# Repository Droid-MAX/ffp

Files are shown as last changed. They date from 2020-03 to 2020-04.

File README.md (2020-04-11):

# FFP: Flash/FPGA Programmer

FFP is a dead-simple USB to bidirectional SPI bridge for programming iCE40
FPGAs and their SPI flash. The hardware is an STM32F042 and not much else.
Firmware and host software is written in Rust.

The firmware additionally supports SWD via the CMSIS-DAP v1 protocol,
so many debuggers such as [probe-rs], [OpenOCD], and [pyOCD] are able to
use an FFP to debug and program Cortex-M and other microcontrollers.

[probe-rs]: https://probe.rs
[OpenOCD]: http://openocd.org
[pyOCD]: https://github.com/mbedmicro/pyOCD

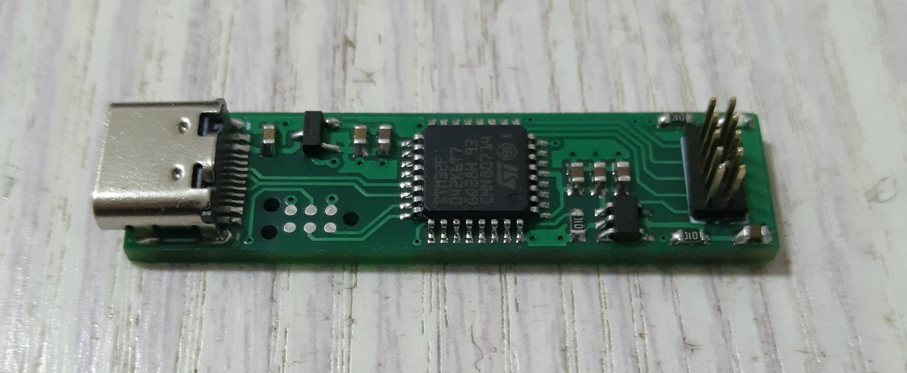
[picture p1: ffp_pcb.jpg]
Photo of FFP PCB


See [software/](software/) for the host-side software, [firmware/](firmware/)
for the embedded device firmware, and [hardware/](hardware/ffp/) for the
hardware design files.

## Pinout

The FFP r1 hardware uses a 5x2 pin 0.05"-pitch connector, which is also
commonly used for Cortex family microcontrollers for SWD and JTAG. The pinout
is deliberately compatible (though note `RESET` is moved) to allow hardware
reuse and for compatibility with tools such as TagConnect cables.

```ascii
          ______
    3v3 --|1  2|-- FLASH DI / FPGA DO / SWDIO
    GND --|3  4|-- CLK / SWCLK
    GND --|5  6|-- CS / SWO
   NULL --|7  8|-- FPGA nRST
    GND --|9 10|-- FLASH DO / FPGA DI / nRESET
          ------

```

This is the same pinout used by
[amp_flashprog](https://github.com/adamgreig/amp_flashprog), a custom firmware
for [Black Magic Probes](https://github.com/blacksphere/blackmagic) to bitbang
SPI to the same ends.

## Licence

Software and firmware is licensed under either of

* Apache License, Version 2.0 ([LICENSE-APACHE](LICENSE-APACHE) or
  http://www.apache.org/licenses/LICENSE-2.0)
* MIT license ([LICENSE-MIT](LICENSE-MIT) or http://opensource.org/licenses/MIT)

at your option.

Hardware design files are licensed under the Creative Commons Attribution
license ([CC-BY](https://creativecommons.org/licenses/by/4.0/)).

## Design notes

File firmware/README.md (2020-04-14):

# FFP Firmware

## Requirements

* You must have a working Rust compiler installed. Visit
[rustup.rs](https://rustup.rs) to install Rust.

* Your Rust toolchain needs the `thumbv6m-none-eabi` target installed:

```
rustup target add thumbv6m-none-eabi
```

## Building

Once Rust is installed, use Cargo to build:

```
cargo build --release
```

The resulting binary is an ELF file in
`target/thumbv6m-none-eabi/release/ffp_firmware` which can be programmed via
your usual programmer, or see below for generating a raw binary file and
bootloading over USB.

## Bootloading

You can reprogram the FFP using its built-in USB bootloader. You can use
[dfu-util](http://dfu-util.sourceforge.net/) or
[STM32CubeProg](https://www.st.com/en/development-tools/stm32cubeprog.html)
to perform the bootloading, both of which are available for Linux, MacOS, and
Windows.

To generate a binary file suitable for bootloading with dfu-util:
```
cargo build --release
arm-none-eabi-objcopy -O binary -S target/thumbv6m-none-eabi/release/ffp_firmware ffp.bin
```

STM32CubeProg can load data directly from the ELF file, but only if it has a
`.elf` extension. Simply copy the elf file:

```
cp target/thumbv6m-none-eabi/release/ffp_firmware ffp_firmware.elf
```

To put an already-programmed FFP device into bootload mode:
```
ffp bootload
```
Devices which have a totally erased flash will come up in bootloader mode
automatically.

To bootload using dfu-util:
```
dfu-suffix -a ffp.bin -v 0483 -p df11
dfu-util -a 0 -s 0x08000000 -D ffp.bin
```

To bootload using STM32CubeProg, open the `ffp_firmware.elf` file made above,
and download it to the FFP.

Reconnect the device after programming to load new firmware.

## Licence

Licensed under either of

* Apache License, Version 2.0 ([LICENSE-APACHE](../LICENSE-APACHE)
  or http://www.apache.org/licenses/LICENSE-2.0 )
* MIT license ([LICENSE-MIT](../LICENSE-MIT) or
  http://opensource.org/licenses/MIT )

at your option.

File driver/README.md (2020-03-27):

# FFP Platform-Specific Drivers

## Linux

Copy the `99-ffp.rules` file to your udev configuration directory and restart
udev:

```
sudo cp 99-ffp.rules /etc/udev/rules.d
sudo udevadm control --reload
```

Confirm you are in the `plugdev` group, or modify `99-ffp.rules` to use another
group or specify a specific user.

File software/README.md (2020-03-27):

# FFP Control Software

The control software for FFP runs on your computer and uses the FFP hardware to
program an FPGA or SPI flash. It is written in Rust.

## Building

```
cargo build --release
```

## Installing

FFP software can be installed using Cargo:

```
cargo install ffp
```

You'll need to set up permissions to access the USB device, see the [drivers
file](/driver/) for more details.

## Usage

Run `ffp help` for detailed usage. Commonly used commands:

* `ffp fpga program bitstream.bin`
* `ffp fpga reset`
* `ffp fpga power on`
* `ffp flash id`
* `ffp flash program bitstream.bin`

## Python Alternative

The prototype for this software was written as a Python script which is also
available ([prog.py](/scripts/prog.py)).

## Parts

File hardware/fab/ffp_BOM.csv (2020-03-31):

Comment | Description | Designator | Footprint | LibRef | Pins | Quantity | PartNumber | url
1µ | desc | C6,C5, | 0603 | libref | 2 | 2
100n | desc | C7,C4,C3,C2,C1, | 0603 | libref | 2 | 5
LED | desc | D1, | 0603-LED | libref | 2 | 1
STM32F042K6T7 | desc | IC1, | LQFP-32 | libref | 32 | 1
MCP1700 | desc | IC2, | SOT-23 | libref | 3 | 1
MIC2004-0_5YM5 | desc | IC3, | SOT-23-5 | libref | 5 | 1
10k | desc | R3,R2,R1, | 0603 | libref | 2 | 3
Through Hole Items
USB_C_Receptacle_USB2.0 | desc | J2, | USB-C_16Pin | libref | 18 | 1
PROG | desc | J3, | PinHeader_2x05_P1.27mm_Vertical | libref | 10 | 1
SWD_TC | desc | P1, | TC2030-NL | libref | 9 | 1

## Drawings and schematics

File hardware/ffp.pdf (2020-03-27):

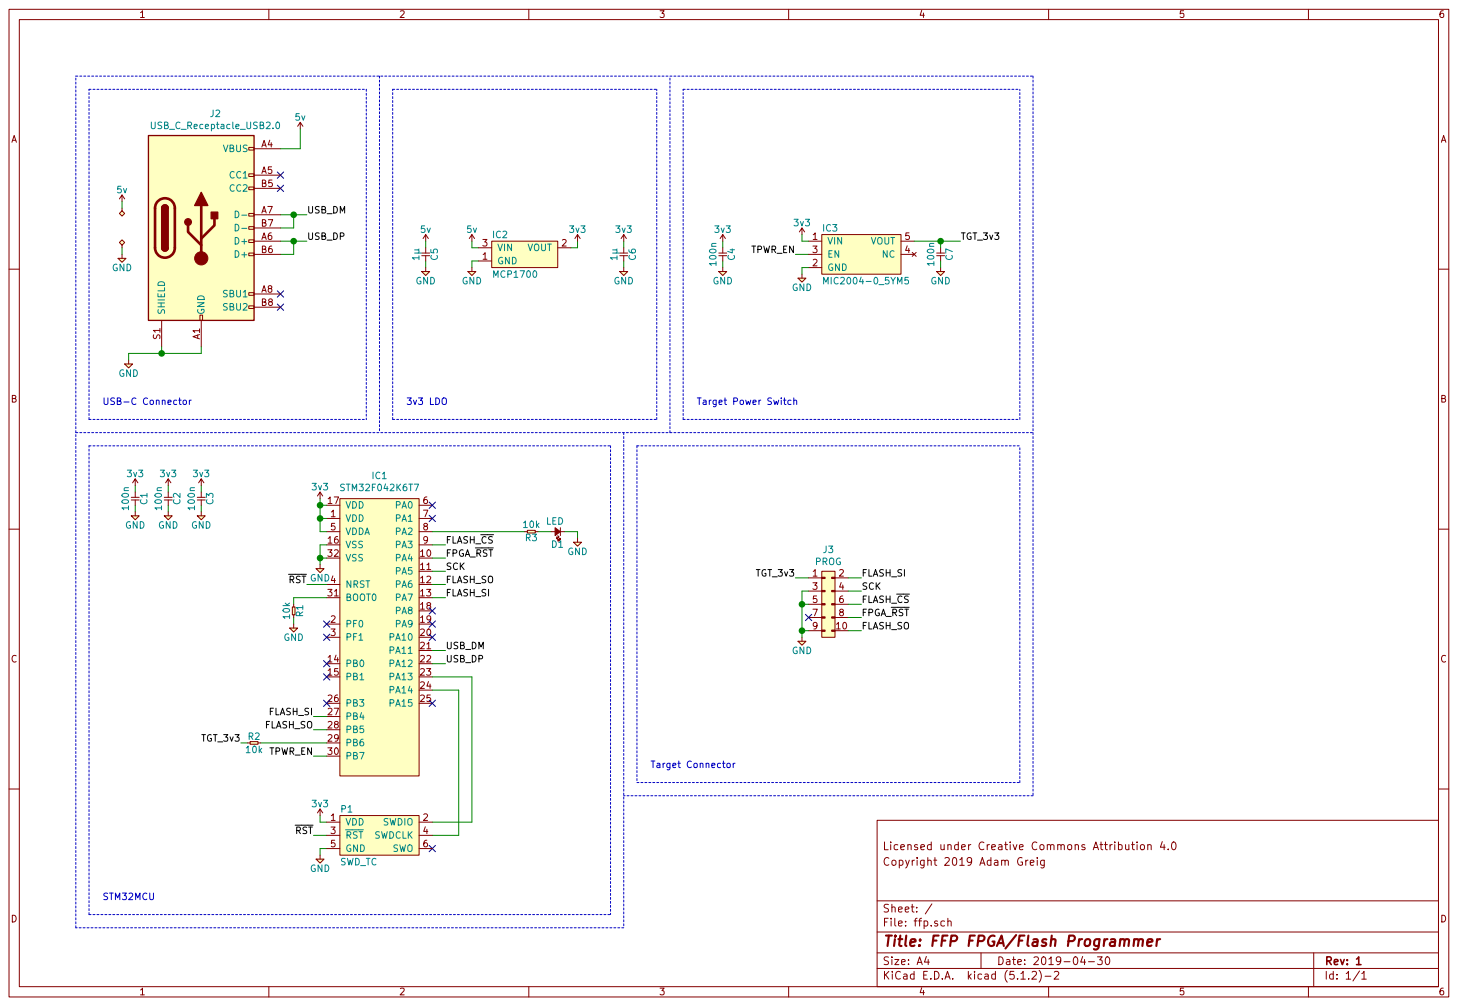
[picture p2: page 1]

Licensed under Creative Commons Attribution 4.0
File: ffp.sch Sheet: / Copyright 2019 Adam Greig

Id: 1/1 Title: FFP FPGA/Flash Programmer

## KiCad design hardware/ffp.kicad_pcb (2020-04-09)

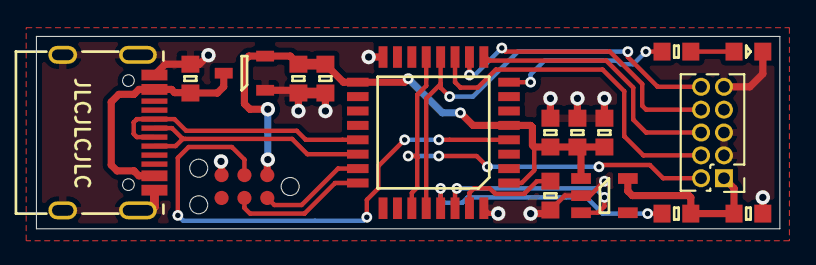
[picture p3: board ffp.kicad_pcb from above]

Board: 2 copper layers, 41.3 x 10.7 mm, 17 parts (0 on the bottom side), 19 nets.

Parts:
C1, C2, C3, C4, C7: 100n; 0603
C5, C6: 1µ; 0603
D1: LED; 0603-LED
IC1: STM32F042K6T7; LQFP-32
IC2: MCP1700; SOT-23
IC3: MIC2004-0_5YM5; SOT-23-5
J2: USB_C_Receptacle_USB2.0; USB-C_16Pin
J3: PROG; PinHeader_2x05_P1.27mm_Vertical
P1: SWD_TC; TC2030-NL
R1, R2, R3: 10k; 0603

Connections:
3v3: C1.1, C2.1, C3.1, C4.1, C6.1, IC1.1, IC1.5, IC1.17, IC2.2, IC3.1, P1.1
5v: C5.1, IC2.3, J2.A4, J2.B4
/FLASH_SI: IC1.13, IC1.27, J3.2
/FLASH_SO: IC1.12, IC1.28, J3.10
/FLASH_~CS: IC1.9, J3.6
/FPGA_~RST: IC1.10, J3.8
/SCK: IC1.11, J3.4
/TGT_3v3: C7.1, IC3.5, J3.1, R2.1
/TPWR_EN: IC1.30, IC3.3
/USB_DM: IC1.21, J2.A7, J2.B7
/USB_DP: IC1.22, J2.A6, J2.B6
/~RST: IC1.4, P1.3
GND: C1.2, C2.2, C3.2, C4.2, C5.2, C6.2, C7.2, D1.1, IC1.16, IC1.32, IC2.1, IC3.2, J2.A1, J2.B1, J2.S1, J3.3, J3.5, J3.9, P1.5, R1.2
unnamed: D1.2, R3.1
unnamed: IC1.8, R3.2
unnamed: IC1.23, P1.2
unnamed: IC1.24, P1.4
unnamed: IC1.29, R2.2
unnamed: IC1.31, R1.1

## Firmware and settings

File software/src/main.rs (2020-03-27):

use std::fs::File;
use std::io::prelude::*;
use std::time::Instant;
use clap::{Arg, App, AppSettings, SubCommand};
use clap::{value_t, crate_authors, crate_description, crate_version};
use ffp::{Programmer, Flash, FPGA};

fn main() -> ffp::Result<()> {
    let matches = App::new("ffp fpga/flash programmer")
        .version(crate_version!())
        .author(crate_authors!("\n"))
        .about(crate_description!())
        .setting(AppSettings::SubcommandRequiredElseHelp)
        .global_setting(AppSettings::ColoredHelp)
        .global_setting(AppSettings::DeriveDisplayOrder)
        .global_setting(AppSettings::GlobalVersion)
        .global_setting(AppSettings::InferSubcommands)
        .global_setting(AppSettings::VersionlessSubcommands)
        .arg(Arg::with_name("quiet")
             .help("Suppress informative output")
             .long("quiet")
             .short("q")
             .global(true))
        .arg(Arg::with_name("serial")
             .help("Serial number of FFP device to use")
             .long("serial")
             .short("s")
             .takes_value(true)
             .global(true))
        .arg(Arg::with_name("index")
             .help("Index of FFP device to use")
             .long("index")
             .short("i")
             .conflicts_with("serial")
             .takes_value(true)
             .global(true))
        .subcommand(SubCommand::with_name("fpga")
            .about("Reset, power, and program the FPGA")
            .setting(AppSettings::SubcommandRequiredElseHelp)
            .subcommand(SubCommand::with_name("reset")
                        .about("Reset the FPGA"))
            .subcommand(SubCommand::with_name("power")
                        .about("Control FPGA power from FFP board")
                        .arg(Arg::with_name("power")
                             .possible_values(&["on", "off"])
                             .required(true)))
            .subcommand(SubCommand::with_name("program")
                        .about("Program FPGA with bitstream")
                        .arg(Arg::with_name("file")
                             .help("File to program to FPGA")
                             .required(true))))
        .subcommand(SubCommand::with_name("flash")
            .about("Read/write flash memory")
            .setting(AppSettings::SubcommandRequiredElseHelp)
            .subcommand(SubCommand::with_name("id")
                        .about("Read flash ID"))
            .subcommand(SubCommand::with_name("erase")
                        .about("Completely erase flash"))
            .subcommand(SubCommand::with_name("program")
                        .about("Program flash chip with binary data from file")
                        .arg(Arg::with_name("file")
                             .help("File to write to flash")
                             .required(true))
                        .arg(Arg::with_name("offset")
                             .help("Start address (in bytes) to read from")
                             .long("offset")
                             .default_value("0"))
                        .arg(Arg::with_name("no-verify")
                             .help("Disable automatic readback verification")
                             .short("n")
                             .long("no-verify")))
            .subcommand(SubCommand::with_name("read")
                        .about("Read contents of flash chip to file")
                        .arg(Arg::with_name("file")
                             .help("File to write with contents of flash")
                             .required(true))
                        .arg(Arg::with_name("length")
                             .help("Length (in bytes) to read from flash")
                             .long("length")
                             .default_value("135183"))
                        .arg(Arg::with_name("offset")
                             .help("Start address (in bytes) to read from")
                             .long("offset")
                             .default_value("0"))))
        .subcommand(SubCommand::with_name("bootload")
            .about("Reset FFP hardware into USB bootloader"))
        .subcommand(SubCommand::with_name("devices")
            .about("List available FFP devices"))
        .get_matches();

    let t0 = Instant::now();
    let context = libusb::Context::new().expect("Error getting libusb context");
    let quiet = matches.is_present("quiet");

    // Special-case devices which does not need a programmer
    if matches.subcommand_name().unwrap() == "devices" {
        let devices = Programmer::get_serials(&context)?;
        match devices.len() {
            0 => println!("No FFP devices found."),
            _ => {
                match devices.len() {
                    1 => println!("1 device found:"),
                    _ => println!("{} devices found:", devices.len()),
                }
                for (idx, serial) in devices.iter().enumerate() {
                    println!("    {}: {}", idx, serial);
                }
            },
        }
        return Ok(());
    }

    let programmer = if matches.is_present("serial") {
        Programmer::by_serial(&context, matches.value_of("serial").unwrap())
    } else if matches.is_present("index") {
        Programmer::by_index(&context, value_t!(matches.value_of("index"), usize).unwrap())
    } else {
        Programmer::find(&context)
    }?;

    match matches.subcommand_name() {
        Some("fpga") => {
            let fpga = FPGA::new(&programmer);
            let matches = matches.subcommand_matches("fpga").unwrap();
            match matches.subcommand_name() {
                Some("reset") => {
                    if !quiet { println!("Resetting FPGA") };
                    fpga.reset()?;
                },
                Some("power") => {
                    let matches = matches.subcommand_matches("power").unwrap();
                    let arg = matches.value_of("power").unwrap();
                    if arg == "on" {
                        if !quiet { println!("Turning on target power") };
                        fpga.power_on()?;
                    } else if arg == "off" {
                        if !quiet { println!("Turning off target power") };
                        fpga.power_off()?;
                    }
                },
                Some("program") => {
                    if !quiet { println!("Programming FPGA") };
                    let matches = matches.subcommand_matches("program").unwrap();
                    let path = matches.value_of("file").unwrap();
                    let mut file = File::open(path)?;
                    let mut data = Vec::new();
                    file.read_to_end(&mut data)?;
                    fpga.program(&data)?;
                },
                _ => panic!(),
            }
        },
        Some("flash") => {
            let flash = Flash::new(&programmer);
            let id = flash.read_id().expect("Error reading flash ID");
            if !quiet { println!("Flash ID: {}", id) };
            let matches = matches.subcommand_matches("flash").unwrap();
            match matches.subcommand_name() {
                Some("id") => {
                    if quiet { println!("Flash ID: {}", id) };
                },
                Some("erase") => {
                    if !quiet { println!("Erasing flash") };
                    flash.erase()?;
                },
                Some("program") => {
                    if !quiet { println!("Programming flash") };
                    let matches = matches.subcommand_matches("program").unwrap();
                    let path = matches.value_of("file").unwrap();
                    let offset = value_t!(matches.value_of("offset"), u32).unwrap();
                    let verify = !matches.is_present("no-verify");
                    let mut file = File::open(path)?;
                    let mut data = Vec::new();
                    file.read_to_end(&mut data)?;
                    flash.program(offset, &data, verify)?;
                    programmer.unreset()?;
                },
                Some("read") => {
                    if !quiet { println!("Reading flash to file") };
                    let matches = matches.subcommand_matches("read").unwrap();
                    let path = matches.value_of("file").unwrap();
                    let offset = value_t!(matches.value_of("offset"), u32).unwrap();
                    let length = value_t!(matches.value_of("length"), usize).unwrap();
                    let mut file = File::create(path)?;
                    let data = flash.read(offset, length)?;
                    file.write_all(&data)?;
                },
                _ => panic!(),
            }
        },
        Some("bootload") => {
            if !quiet { println!("Resetting FFP into bootloader") };
            programmer.bootload()?;
        },
        _ => panic!(),
    };

    let t1 = t0.elapsed();
    if !quiet { println!("Finished in {}.{:02}s", t1.as_secs(), t1.subsec_millis()/10) };

    Ok(())
}

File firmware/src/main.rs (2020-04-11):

// Copyright 2019 Adam Greig
// Dual licensed under the Apache 2.0 and MIT licenses.

#![no_std]
#![no_main]

extern crate panic_halt;
use cortex_m_rt::{entry, pre_init};
use git_version::git_version;

const GIT_VERSION: &str = git_version!();

pub mod hal;
pub mod app;
pub mod swd;
pub mod dap;

#[pre_init]
unsafe fn pre_init() {
    // Check if we should jump to system bootloader.
    //
    // When we receive the BOOTLOAD command over USB,
    // we write a flag to a static and reset the chip,
    // and `bootload::check()` will jump to the system
    // memory bootloader if the flag is present.
    //
    // It must be called from pre_init as otherwise the
    // flag is overwritten when statics are initialised.
    hal::bootload::check();
}

#[entry]
fn main() -> ! {
    let flash = hal::flash::Flash::new(stm32ral::flash::Flash::take().unwrap());
    let rcc = hal::rcc::RCC::new(stm32ral::rcc::RCC::take().unwrap(),
                                 stm32ral::crs::CRS::take().unwrap());
    let nvic = hal::nvic::NVIC::new(stm32ral::nvic::NVIC::take().unwrap(),
                                    stm32ral::scb::SCB::take().unwrap());
    let dma = hal::dma::DMA::new(stm32ral::dma1::DMA1::take().unwrap());
    let gpioa = hal::gpio::GPIO::new(stm32ral::gpio::GPIOA::take().unwrap());
    let gpiob = hal::gpio::GPIO::new(stm32ral::gpio::GPIOB::take().unwrap());
    let spi = hal::spi::SPI::new(stm32ral::spi::SPI1::take().unwrap());
    let mut usb = hal::usb::USB::new(stm32ral::usb::USB::take().unwrap());

    // Define pinout.
    // Some pins are defined early so we can memoise their modes for
    // faster mode switching at runtime.
    let sck = gpioa.pin(5);
    let flash_si = gpioa.pin(7);
    let flash_si_input_mode = flash_si.memoise_mode_input();
    let flash_si_alternate_mode = flash_si.memoise_mode_alternate();
    let sck_output_mode = sck.memoise_mode_output();
    let sck_alternate_mode = sck.memoise_mode_alternate();
    let pins = hal::gpio::Pins {
        led: gpioa.pin(2),
        cs: gpioa.pin(3),
        fpga_rst: gpioa.pin(4),
        sck,
        flash_so: gpioa.pin(6),
        flash_si,
        fpga_so: gpiob.pin(4),
        fpga_si: gpiob.pin(5),
        tpwr_det: gpiob.pin(6),
        tpwr_en: gpiob.pin(7),

        flash_si_input_mode,
        flash_si_alternate_mode,
        sck_output_mode,
        sck_alternate_mode,
    };

    let swd = swd::SWD::new(&spi, &pins);
    let mut dap = dap::DAP::new(swd, &pins);

    // Create App instance with the HAL instances
    let mut app = app::App::new(&flash, &rcc, &nvic, &dma, &pins, &spi, &mut usb, &mut dap);

    // Initialise application, including system peripherals
    app.setup();

    loop {
        // Process events
        app.poll();
    }
}

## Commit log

2020-03-27 replace usb4085 package of type-c interface to 16pin package
    [ffp-B_Cu.gbl, ffp-B_Mask.gbs, ffp-B_Paste.gbp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]
2020-03-28 adjust the border and remove the top copper
    [ffp-B_Cu.gbl, ffp-B_Mask.gbs, ffp-B_Paste.gbp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]
2020-03-28 update gerber files
    [ffp-B_Cu.gbl, ffp-B_Mask.gbs, ffp-B_Paste.gbp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]
2020-03-28 add dimension for pcb file
    [ffp.kicad_pcb]
2020-03-28 fix dimension layer to F.Fab
    [ffp.kicad_pcb]
2020-03-29 detail adjustment
    [ffp.kicad_pcb]
2020-03-29 replated copper to the top and updated gerber files
    [ffp-B_Cu.gbl, ffp-B_Mask.gbs, ffp-B_Paste.gbp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]
2020-03-31 replaced the connector with a dual row 5pin header with 1.27mm pitch
    [ffp-B_Cu.gbl, ffp-B_Mask.gbs, ffp-B_Paste.gbp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]
2020-04-06 optimized USB differential line routing
    [ffp-B_Cu.gbl, ffp-B_Mask.gbs, ffp-B_Paste.gbp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]
2020-04-09 fix some detail problems on F.Fab
    [ffp.kicad_pcb]
